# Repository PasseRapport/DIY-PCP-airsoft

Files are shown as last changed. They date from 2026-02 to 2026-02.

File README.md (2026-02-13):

# DIY-PCP-airsoft

Cheap and powerful DIY airsoft gun

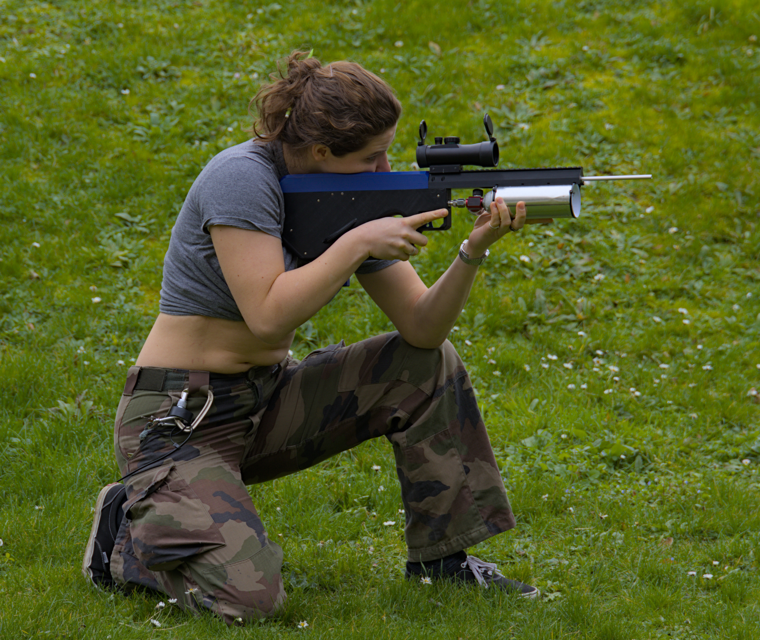
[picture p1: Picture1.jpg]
<br>

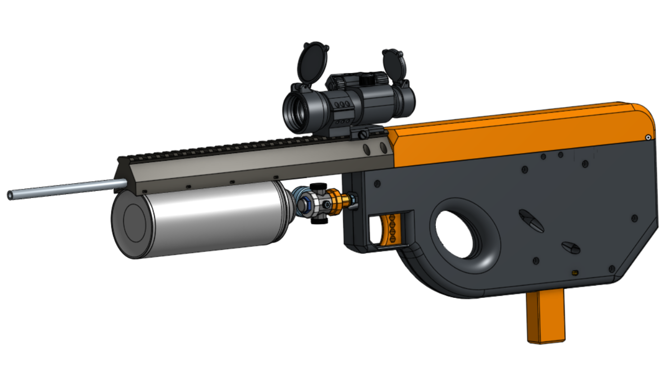
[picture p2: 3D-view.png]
<br>

I tried to build the cheapest airsoft gun without sacrificing power and accuracy. Also without using any off the shelf airsoft parts. The power source is a paint can pumped to a 10bar max pressure with a bike pump. It make the build cheap to run as the only consumables are the bb's.

The air is delivered to the hop-up unit by a solenoid valve. The automatic reloading after each shot is managed by a small servo. The brain of all this is an Arduino Nano wich has three switch connected to it : trigger switch hidden inside, safety switch, fire mode switch

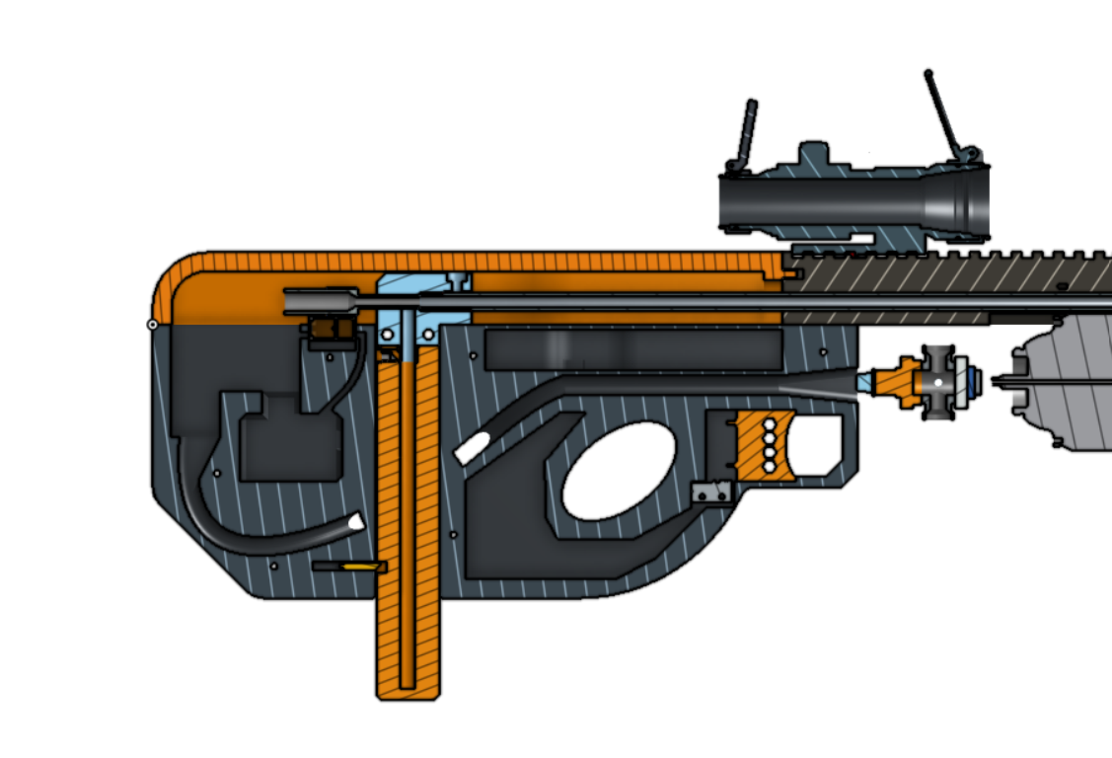
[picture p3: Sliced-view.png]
<br>

<br>

<br>

Everything is powered by a 18650 cell and a buck-boost converter

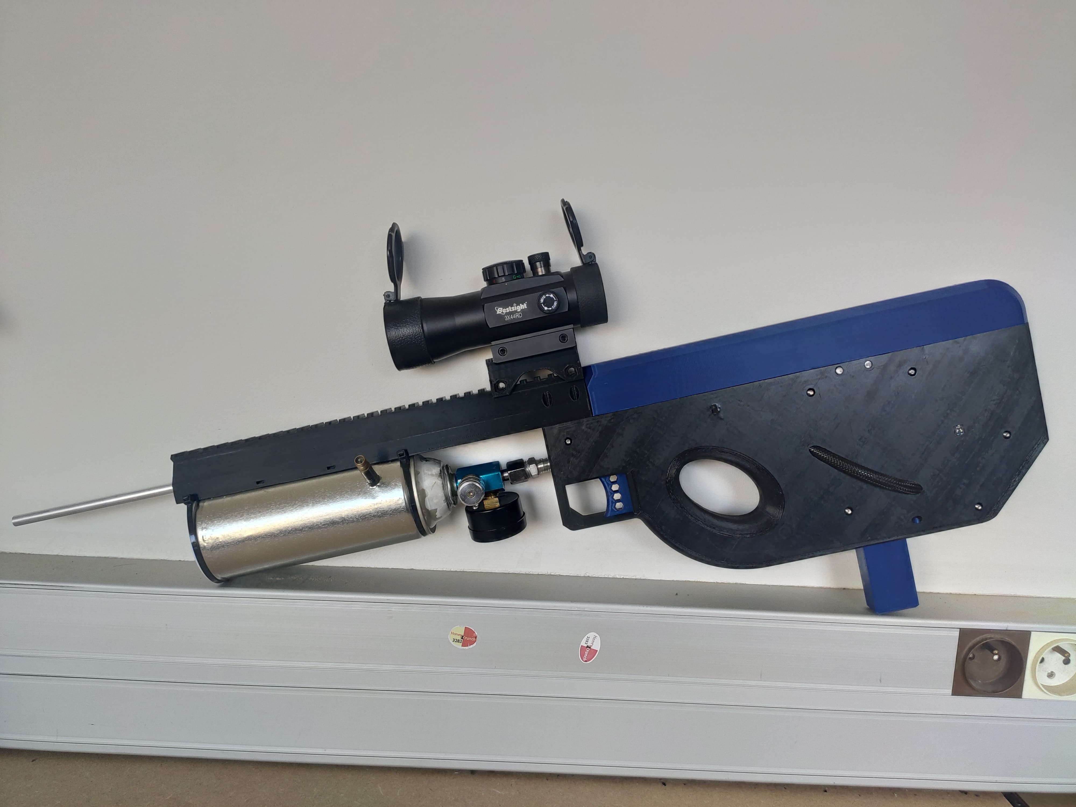
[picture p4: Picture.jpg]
<br>

The magasine can hold 25 bb and a full tank of air will last me 3 magazines. I know that it cannot compete whith a high end airsoft replica but i'm very happy of the results. It has a great accuracy, more power than needed and it can be built for less than 50€ !!!!

You'll find here all the 3D files, the bill of materials, the wiring diagram and the code.

I took inspiration from this \[project](https://github.com/AlexGyver/EnglishProjects/tree/master/GyverGun)

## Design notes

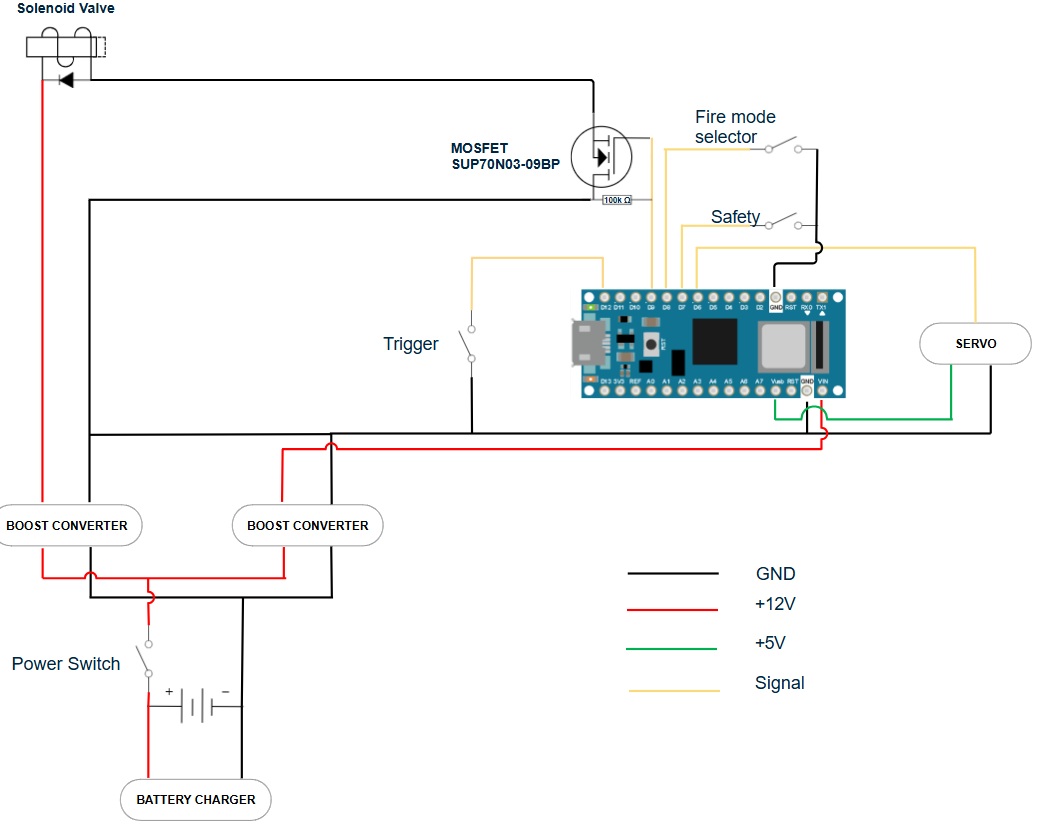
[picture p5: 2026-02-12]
Electronics/Schematic.png

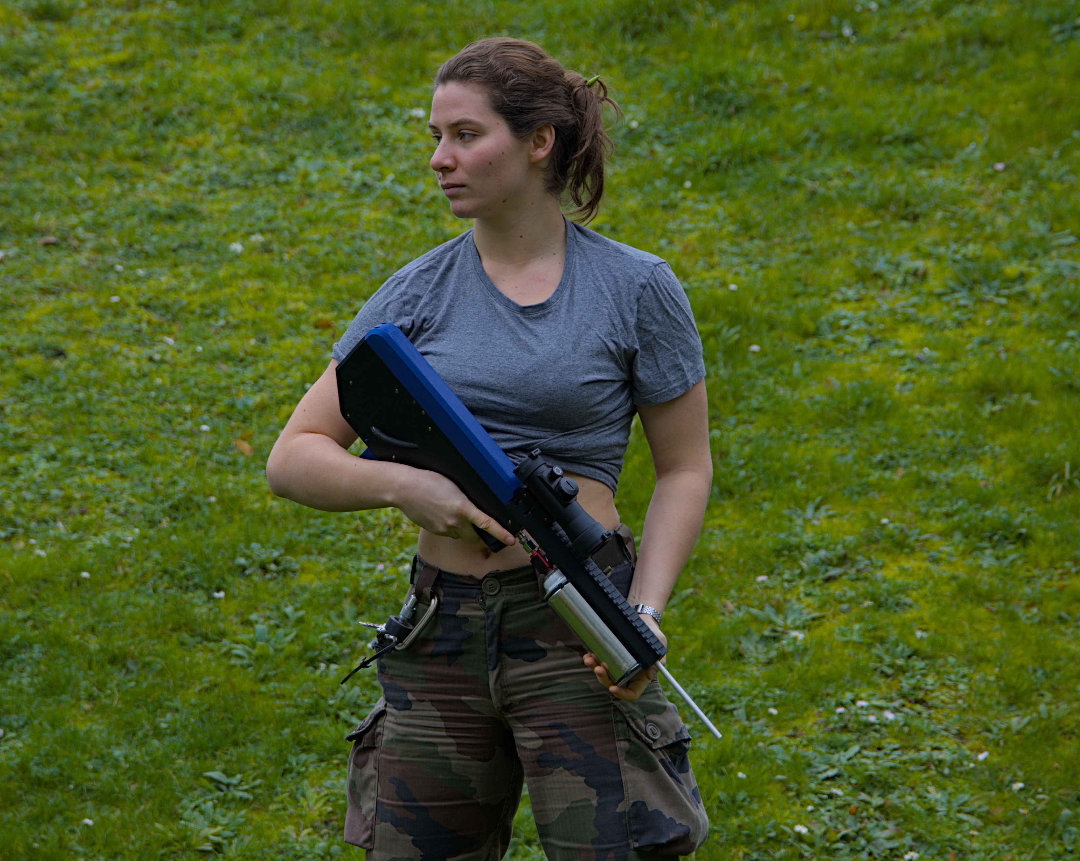
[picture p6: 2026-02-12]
Picture2.jpg

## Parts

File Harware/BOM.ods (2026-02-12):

Parts | Quantity | Where to find
M3x30mm | 8 | link (https://nl.aliexpress.com/item/1005007475378895.html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)
M3x20mm | 6
M3x6mm | 2
M3 inserts | 6 | link (https://nl.aliexpress.com/item/1005003582355741.html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)
5mm rod | > 6cm | hardware store
6mm O-ring | 1 | link (https://nl.aliexpress.com/item/1005006755981142.html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)
magazine spring 0.4x6x300mm | 1 | link (https://www.aliexpress.com/item/1005003776003249.html)
6x1mm aluminium or steel pipe | > 50 cm | hardware store
8x5mm tubing | > 60 cm | link (https://nl.aliexpress.com/item/4001000876771.html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)
6x1mm tubing | > 5 cm
Pressure regulator | 1 | link (https://nl.aliexpress.com/item/1005007285924544.html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)
Microswitch | 1 | link (https://nl.aliexpress.com/item/1005006047541264.html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)
Arduino/ESP32 | 1 | Arduino (https://www.alldatasheet.fr/datasheet-pdf/pdf/87299/VISHAY/SUP70N03-09BP.html) | ESP32 (https://www.aliexpress.com/item/1005006599448997.html)
Battery cell | 1 | Salvage from an old E-cigarette
Battery charger |  | link (https://www.aliexpress.com/item/1005006414844459.html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)
Solenoid valve | 1 | link (https://nl.aliexpress.com/item/1005005245082265.html)
Transistor MOSFET SUP70N03-09BP | 1 | link (https://www.aliexpress.com/item/1005001344824282.html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) | Datsheet (https://www.alldatasheet.fr/datasheet-pdf/pdf/87299/VISHAY/SUP70N03-09BP.html)
Diode | 1 | link (https://www.amazon.fr/Haobase-IN4007-Diode-Redresseur-1000V/dp/B01F4SQ6KU?__mk_fr_FR=ÅMÅŽÕÑ&nsdOptOutParam=true) | Datasheet (https://www.alldatasheet.fr/datasheet-pdf/download/58830/DIODES/1N4007.html)
Boost converter | 2 | link 1 (https://nl.aliexpress.com/item/1005006427245477.html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) | link 2 (https://www.aliexpress.com/item/1005006361814667.html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)
100kΩ Resistor | 1 | link (https://www.amazon.fr/20pcs-Metal-Film-Resistor-100K/dp/B0B3VJ5DVT?__mk_fr_FR=ÅMÅŽÕÑ&nsdOptOutParam=true)
angled ¼ inch Air fitting | 1 | link (https://nl.aliexpress.com/item/1005006956176652.html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)
Small spring | 2 | in any mechanical pencil
Large spring | 1 or 2 | anything that fit will do (max diameter 9mm)
Metal sheet | 1 | Cut it from a metal box

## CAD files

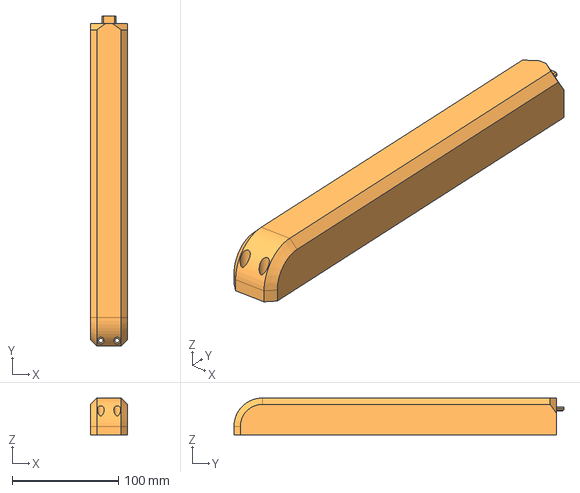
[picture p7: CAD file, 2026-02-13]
Harware/3D_files/Body/cheek rest.step
35.0 x 309.9 x 34.7 mm

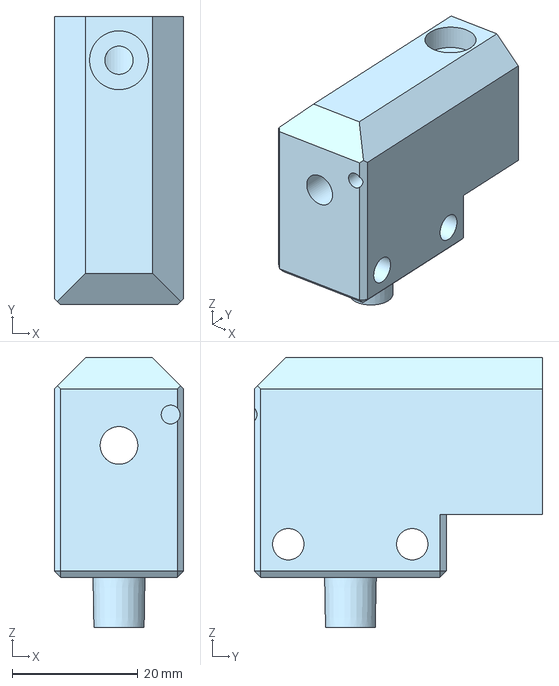
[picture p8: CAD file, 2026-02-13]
Harware/3D_files/HopUp/HopUp - Part 1.step
20.6 x 45.9 x 43.0 mm

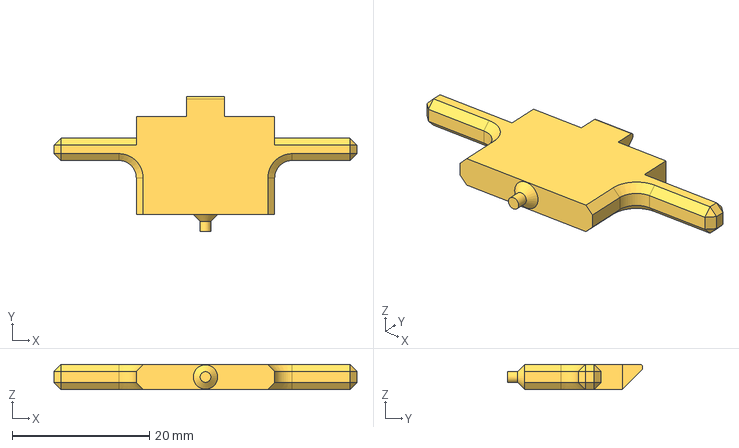
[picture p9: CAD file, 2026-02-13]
Harware/3D_files/Magazine/Mag release.step
44.2 x 19.7 x 3.67 mm

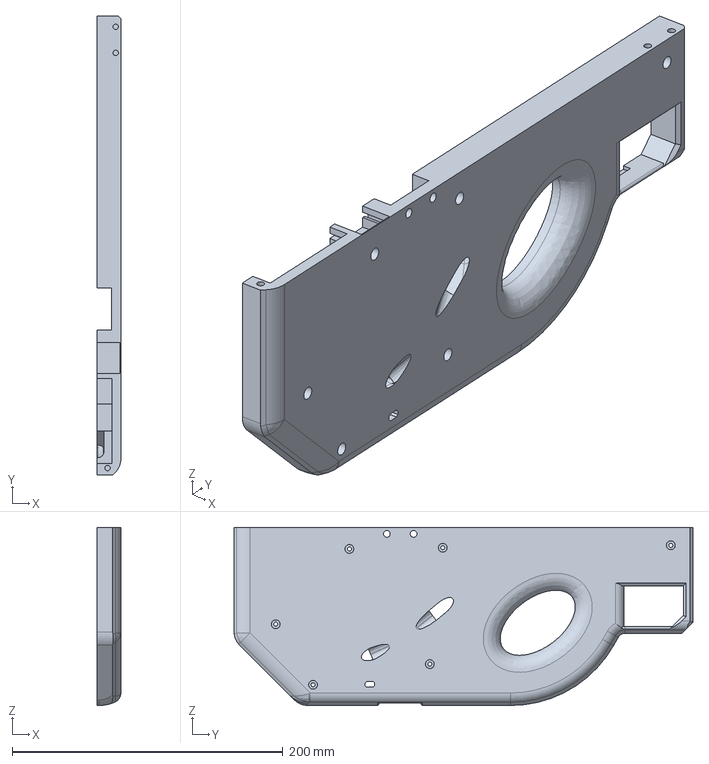
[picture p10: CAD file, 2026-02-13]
Harware/3D_files/Body/Right.step
17.5 x 338.9 x 131.4 mm

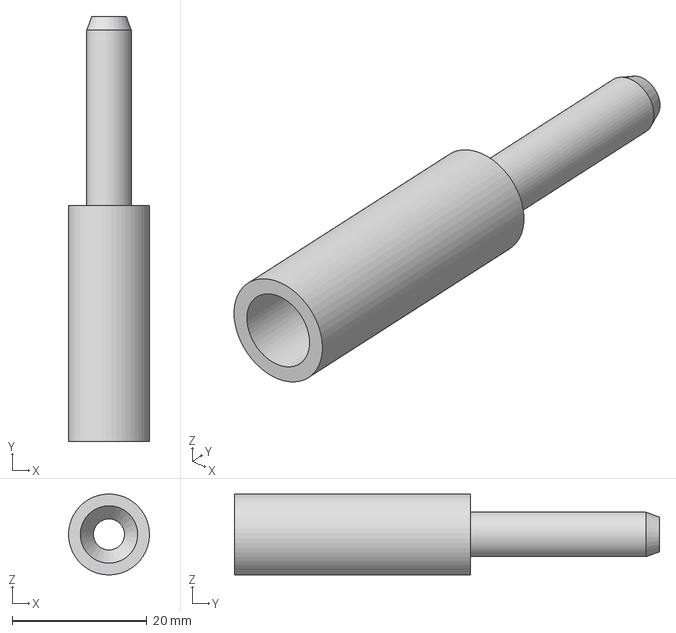
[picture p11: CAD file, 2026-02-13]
Harware/3D_files/HopUp/HopUp - Part 2 (to be made in metal).step
12.0 x 63.0 x 12.0 mm

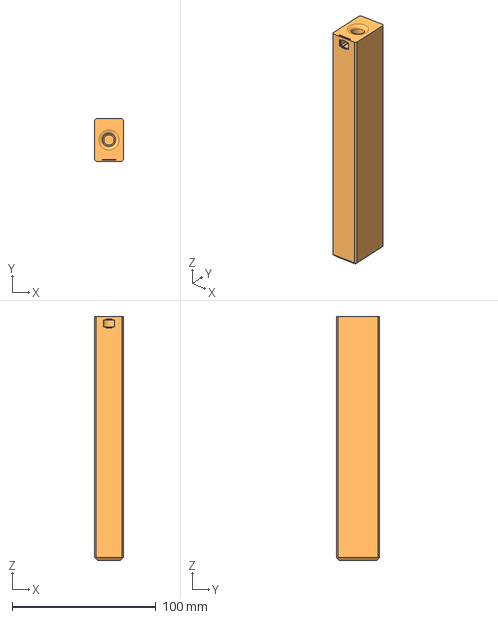
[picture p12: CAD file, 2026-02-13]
Harware/3D_files/Magazine/Mag.step
20.0 x 30.0 x 170.0 mm

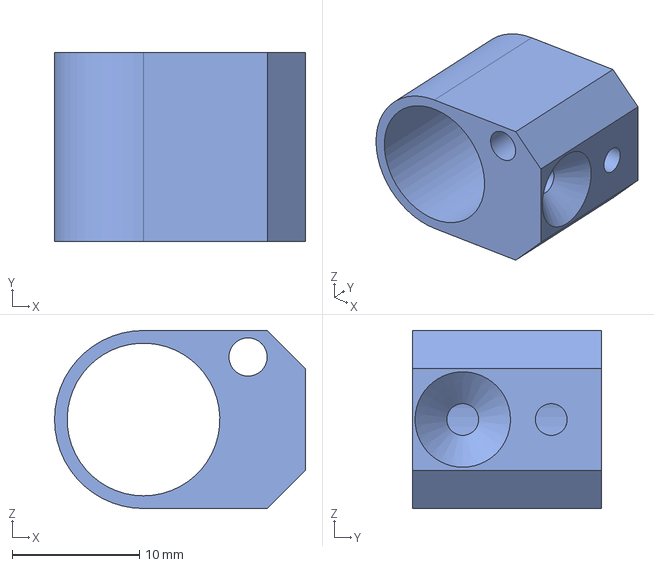
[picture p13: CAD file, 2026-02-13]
Harware/3D_files/HopUp/HopUp - Part 3.step
19.7 x 14.9 x 14.0 mm

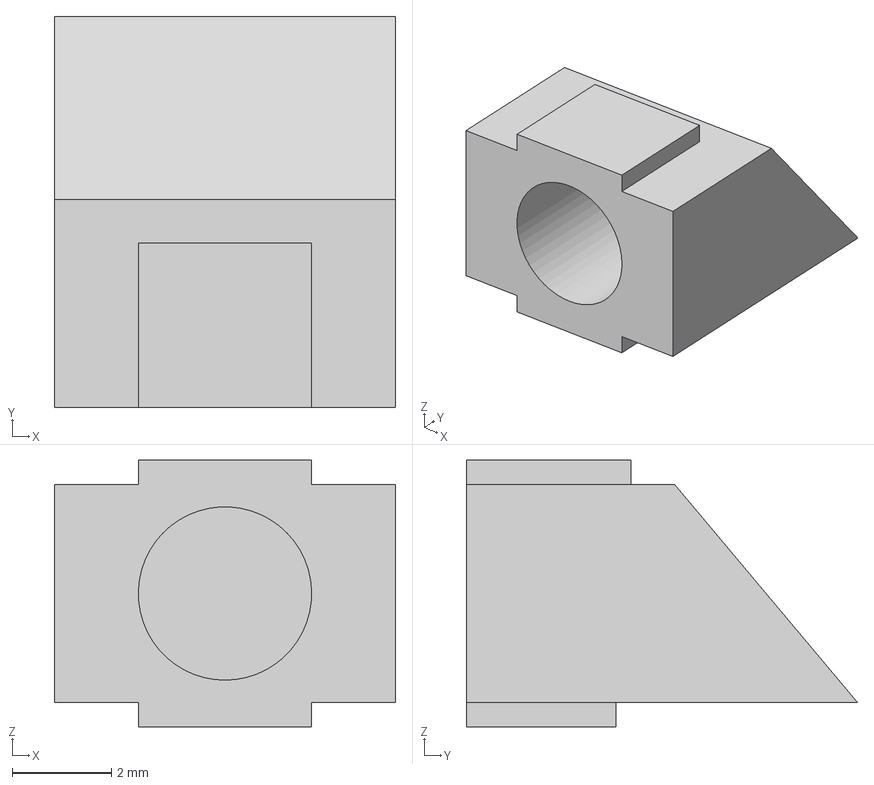
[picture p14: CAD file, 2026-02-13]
Harware/3D_files/Magazine/Slider.step
6.90 x 7.90 x 5.39 mm

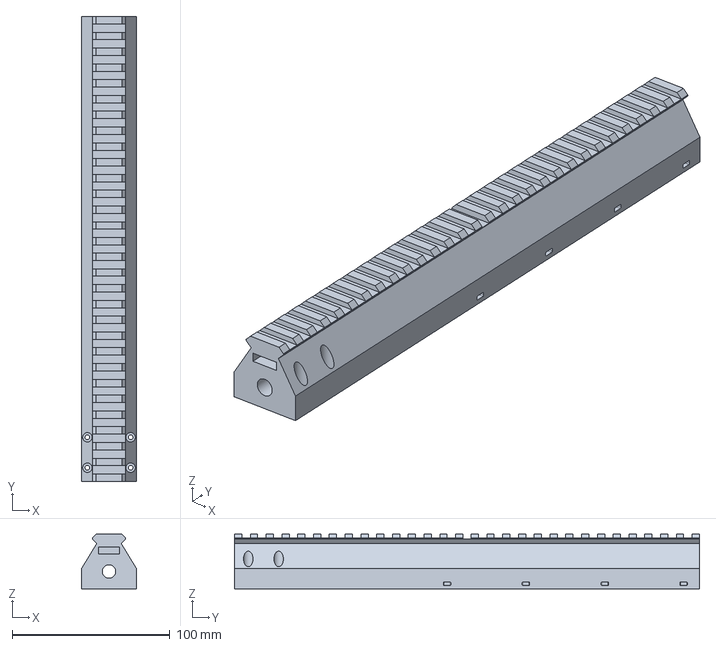
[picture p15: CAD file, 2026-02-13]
Harware/3D_files/Body/Rail.step
35.0 x 294.7 x 34.7 mm

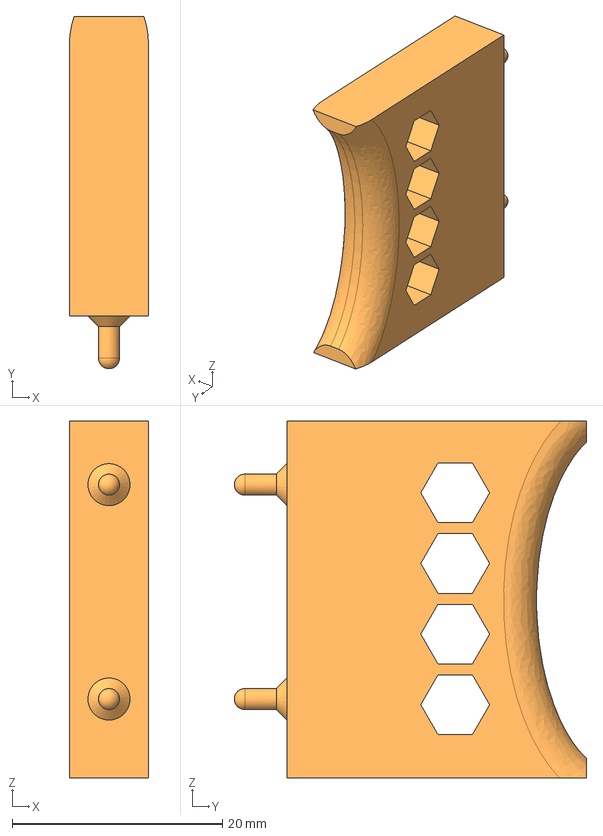
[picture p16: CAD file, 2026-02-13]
Harware/3D_files/Body/Trigger.step
7.50 x 33.5 x 34.0 mm

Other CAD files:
Harware/3D_files/Body/left.step

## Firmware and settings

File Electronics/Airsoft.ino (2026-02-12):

#include <Servo.h>


#define valvePin 9
#define servoPin 6
#define triggerPin 12
#define safetyPin 7
#define fireSelectPin 8


#define boltOpen 135      //Theses are the angle values for the  servo
#define chamberLoaded 105 //
#define fire 85

Servo Servo;

void setup()
{
  
  pinMode(fireSelectPin,INPUT);
  pinMode(valvePin, OUTPUT);
  Servo.attach(servoPin);
  pinMode(triggerPin, INPUT);
 
}

void loop()
{

  while(digitalRead(safetyPin))
  {
    delay(100);
  }

  int fireMode = digitalRead(fireSelectPin);
  

  if(fireMode)               //FULL AUTO
  {
  
    if(digitalRead(triggerPin))
    {
      delay(150);
      Servo.write(fire);
      delay(100);
      digitalWrite(valvePin, HIGH);
      delay(20);                      //Valve open duration
      digitalWrite(valvePin, LOW);

      delay(150);                     //give time to the bullet to leave the cannon

      if(digitalRead(triggerPin))
      {
        Servo.write(boltOpen);        //faster cycle skipping the "chamerLoaded" state      
        delay(100);  
      }
      else
      {
        Servo.write(boltOpen);
        delay(150);
        Servo.write(chamberLoaded);
      }
    }
                             
  }
  else                         //SINGLE FIRE
  {
    if(digitalRead(triggerPin))
    {
      Servo.write(fire);
      delay(100);                       //adding a delay cause the servo is too slow
      digitalWrite(valvePin, HIGH);
      delay(20);                        //Valve open duration
      digitalWrite(valvePin, LOW);
      delay(100);
      Servo.write(90);
      delay(300);                        //give time to the bullet to leave the cannon

      Servo.write(140);
      delay(250);
      Servo.write(chamberLoaded);
      delay(300);
      while(digitalRead(triggerPin))
      {
        
      }
    }
  }
}
